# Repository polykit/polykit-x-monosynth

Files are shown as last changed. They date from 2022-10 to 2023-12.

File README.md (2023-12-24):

# Polykit X1 Semi Modular Synthesizer

This repository contains schematics, PCB layout files and front panel for an analog, semi modular, patchable synthesizer. It is an interface that works in conjunction with my voice card https://github.com/polykit/polykit-x-voice-card

Specs of the voice card:

* a VCO with saw, pulse and triangle signal
* an envelope generator
* a multimode filter with 8 different filter responses
* an external input
* and a panning stereo output

See voice card repository for a full feature list.

Specs of the semi modular interface:

* a LFO where the waveform can be blended between triangle and pulse signal
* a wave folder
* a two channel mixer where one input can be attenuated
* an additional attenuator
* a buffered multiple
* different offset voltages
* and a power supply
* 3D printable case

Video playlist on its functionality and design process: https://www.youtube.com/watch?v=2grRbG7IwDw&list=PLUKLEU8jmlbHH4_13YZM0MI6ez4gYQPfy

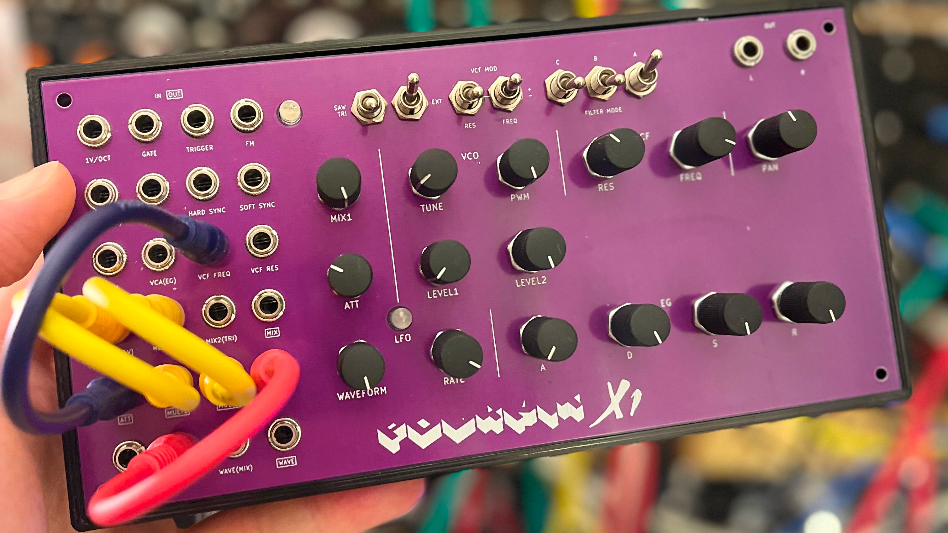
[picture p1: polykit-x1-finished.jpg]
Polykit X1 Semi Modular Synthesizer


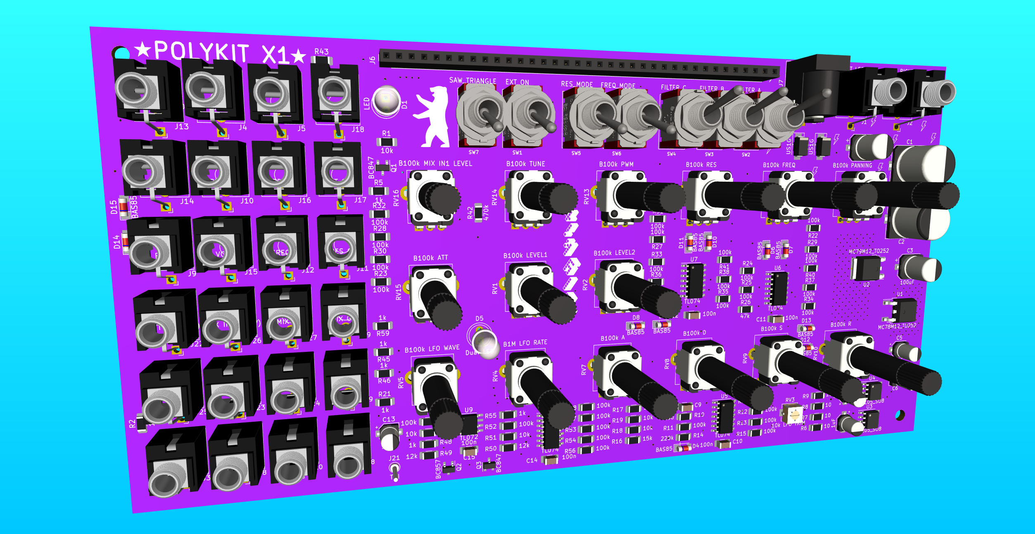
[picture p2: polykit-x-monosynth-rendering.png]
Polykit X1 Semi Modular Synthesizer Rendering


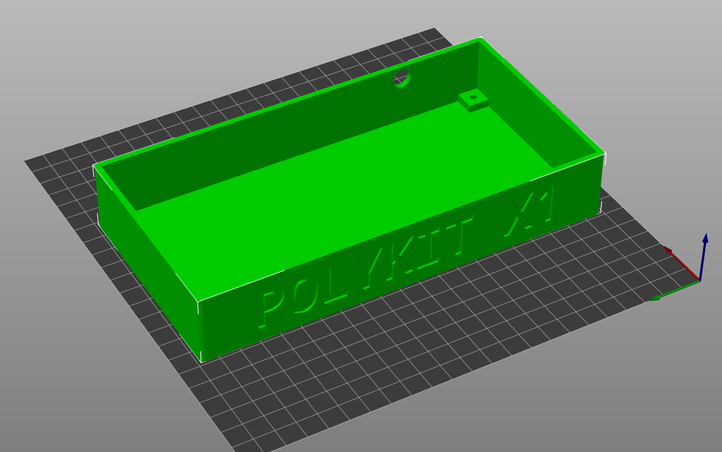
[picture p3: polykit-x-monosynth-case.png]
Polykit X1 Semi Modular Synthesizer Case


Gerber files [can be found here](plots/), front panel files are located [here](frontpanel).

## BOM

|Ref |Qnty|Value |Name |Description |
|---|----|---|---|---|
|C1, C2 |2 |1000uF |C_Polarized |Electrolytic capacitor |
|C3, C4 |2 |100uF |C_Polarized |Electrolytic capacitor |
|C5, C6 |2 |10uF |C_Polarized |Electrolytic capacitor |
|C7, C8 |2 |1uF |C_Polarized |Electrolytic capacitor |
|C9 |1 |2u2 non-polarized |C |Film or ceramic capacitor |
|C10, C11, C12, C13, C14 |5 |100n |C |Ceramic capacitor |
|D1 |1 |LED |LED |Light emitting diode |
|D2, D3 |2 |US1G |US1G |400V, 1A, General Purpose Rectifier Diode, SMA(DO-214AC) |
|D4, D6, D7, D8, D9, D10, D11, D12, D13, D14, D15 |11  |BAS85 |D_Schottky |Schottky diode |
|D5 |1 |Dual LED |LED_Dual_Bidirectional|Dual LED, bidirectional |
|J1 |1 |OUT LEFT |AudioJack2_SwitchT |Audio Jack, 2 Poles (Mono / TS), https://www.thonk.co.uk/shop/thonkiconn|
|J2 |1 |OUT RIGHT |AudioJack2_SwitchT |Audio Jack, 2 Poles (Mono / TS), https://www.thonk.co.uk/shop/thonkiconn|
|J3 |1 |ADSR_OUT |AudioJack2_SwitchT |Audio Jack, 2 Poles (Mono / TS), https://www.thonk.co.uk/shop/thonkiconn|
|J4 |1 |GATE |AudioJack2_SwitchT |Audio Jack, 2 Poles (Mono / TS), https://www.thonk.co.uk/shop/thonkiconn|
|J5 |1 |TRIGGER |AudioJack2_SwitchT |Audio Jack, 2 Poles (Mono / TS), https://www.thonk.co.uk/shop/thonkiconn|
|J6 |1 |Conn_01x36 |Conn_01x36 |Pinheader, 01x36 |
|J7 |1 |12V AC |Jack-DC |Barrel Jack Socket, 12V AC/AC 1A wall wart power supply is needed |
|J8 |1 |LFO |AudioJack2_SwitchT |Audio Jack, 2 Poles (Mono / TS), https://www.thonk.co.uk/shop/thonkiconn|
|J9 |1 |PAN_CV |AudioJack2_SwitchT |Audio Jack, 2 Poles (Mono / TS), https://www.thonk.co.uk/shop/thonkiconn|
|J10 |1 |PWM CV |AudioJack2_SwitchT |Audio Jack, 2 Poles (Mono / TS), https://www.thonk.co.uk/shop/thonkiconn|
|J11 |1 |RES CV |AudioJack2_SwitchT |Audio Jack, 2 Poles (Mono / TS), https://www.thonk.co.uk/shop/thonkiconn|
|J12 |1 |FREQ CV |AudioJack2_SwitchT |Audio Jack, 2 Poles (Mono / TS), https://www.thonk.co.uk/shop/thonkiconn|
|J13 |1 |PITCH CV 1V/OCT |AudioJack2_SwitchT |Audio Jack, 2 Poles (Mono / TS), https://www.thonk.co.uk/shop/thonkiconn|
|J14 |1 |EXT IN |AudioJack2_SwitchT |Audio Jack, 2 Poles (Mono / TS), https://www.thonk.co.uk/shop/thonkiconn|
|J15 |1 |VCA CV |AudioJack2_SwitchT |Audio Jack, 2 Poles (Mono / TS), https://www.thonk.co.uk/shop/thonkiconn|
|J16 |1 |HARD SYNC |AudioJack2_SwitchT |Audio Jack, 2 Poles (Mono / TS), https://www.thonk.co.uk/shop/thonkiconn|
|J17 |1 |SOFT SYNC |AudioJack2_SwitchT |Audio Jack, 2 Poles (Mono / TS), https://www.thonk.co.uk/shop/thonkiconn|
|J18 |1 |FM |AudioJack2_SwitchT |Audio Jack, 2 Poles (Mono / TS), https://www.thonk.co.uk/shop/thonkiconn|
|J19 |1 |MULT |AudioJack2_SwitchT |Audio Jack, 2 Poles (Mono / TS), https://www.thonk.co.uk/shop/thonkiconn|
|J20 |1 |WAVE IN |AudioJack2_SwitchT |Audio Jack, 2 Poles (Mono / TS), https://www.thonk.co.uk/shop/thonkiconn|
|J21 |1 |ATT IN (+5V) |AudioJack2_SwitchT |Audio Jack, 2 Poles (Mono / TS), https://www.thonk.co.uk/shop/thonkiconn|
|J22 |1 |MULT1 |AudioJack2_SwitchT |Audio Jack, 2 Poles (Mono / TS), https://www.thonk.co.uk/shop/thonkiconn|
|J23 |1 |MULT2 |AudioJack2_SwitchT |Audio Jack, 2 Poles (Mono / TS), https://www.thonk.co.uk/shop/thonkiconn|
|J24 |1 |ATT OUT |AudioJack2_SwitchT |Audio Jack, 2 Poles (Mono / TS), https://www.thonk.co.uk/shop/thonkiconn|
|J25 |1 |MIX IN2 | |Can be used as default input for MIX2 when not patched |
|J26 |1 |MIX IN1 (-5V) |AudioJack2_SwitchT |Audio Jack, 2 Poles (Mono / TS), https://www.thonk.co.uk/shop/thonkiconn|
|J27 |1 |MIX IN2 |AudioJack2_SwitchT |Audio Jack, 2 Poles (Mono / TS), https://www.thonk.co.uk/shop/thonkiconn|
|J28 |1 |WAVE OUT |AudioJack2_SwitchT |Audio Jack, 2 Poles (Mono / TS), https://www.thonk.co.uk/shop/thonkiconn|
|J29 |1 |MIX OUT |AudioJack2_SwitchT |Audio Jack, 2 Poles (Mono / TS), https://www.thonk.co.uk/shop/thonkiconn|
|Q1, Q3 |2 |BC847 |BC847 |0.1A Ic, 45V Vce, NPN Transistor, SOT-23 |
|Q2 |1 |BC857 |BC857 |0.1A Ic, 45V Vce, PNP Transistor, SOT-23 |
|R1, R18, R19, R47, R50 |5 |10k |R |Resistor |
|R2, R3, R4, R5, R20, R21, R45, R46, R54, R58 |10  |1k |R |Resistor |
|R10 |1 |100 |R |Resistor |
|R11, R12, R13, R15, R22, R23, R24, R25, R27, R28, R29, R30, R31, R32, R33, R34, R35, R36, R37, R38, R39, R40, R41, R43, R44, R51, R52, R53, R55, R56, R57|31  |100k |R |Resistor |
|R14 |1 |220k |R |Resistor |
|R16 |1 |15k |R |Resistor |
|R17, R48, R49 |3 |12k |R |Resistor |
|R26 |1 |47k |R |Resistor |
|R42 |1 |470k |R |Resistor |
|RV1 |1 |B100k LEVEL1 |R_POT-Device |Potentiometer RK097 Vertical |
|RV2 |1 |B100k LEVEL2 |R_POT-Device |Potentiometer RK097 Vertical |
|RV3 |1 |10k LFO TRIM |R_Potentiometer_Trim  |Trim-potentiometer |
|RV4 |1 |B1M LFO RATE |R_POT-Device |Potentiometer RK097 Vertical |
|RV5 |1 |B100k LFO WAVE |R_POT-Device |Potentiometer RK097 Vertical |
|RV6 |1 |B100k PANNING |R_POT-Device |Potentiometer RK097 Vertical |
|RV7 |1 |B100k A |R_POT-Device |Potentiometer RK097 Vertical |
|RV8 |1 |B100k D |R_POT-Device |Potentiometer RK097 Vertical |
|RV9 |1 |B100k S |R_POT-Device |Potentiometer RK097 Vertical |
|RV10 |1 |B100k R |R_POT-Device |Potentiometer RK097 Vertical |
|RV11 |1 |B100k RES |R_POT-Device |Potentiometer RK097 Vertical |
|RV12 |1 |B100k FREQ |R_POT-Device |Potentiometer RK097 Vertical |
|RV13 |1 |B100k PWM |R_POT-Device |Potentiometer RK097 Vertical |
|RV14 |1 |B100k TUNE |R_POT-Device |Potentiometer RK097 Vertical |
|RV15 |1 |B100k ATT |R_POT-Device |Potentiometer RK097 Vertical |
|RV16 |1 |B100k MIX IN1 LEVEL|R_POT-Device |Potentiometer RK097 Vertical |
|SW1 |1 |EXT_ON |SW_SPDT |Switch, single pole double throw |
|SW2 |1 |FILTER_A |SW_SPDT |Switch, single pole double throw |
|SW3 |1 |FILTER_B |SW_SPDT |Switch, single pole double throw |
|SW4 |1 |FILTER_C |SW_SPDT |Switch, single pole double throw |
|SW5 |1 |RES_MODE |SW_SPDT_MSM |Switch, single pole double throw, center OFF position |
|SW6 |1 |FREQ_MODE |SW_SPDT_MSM |Switch, single pole double throw, center OFF position |
|SW7 |1 |SAW_TRIANGLE |SW_SPDT |Switch, single pole double throw |
|U1 |1 |MC78M12_TO252 |78M12 TO-252 |Positive 500mA 35V Linear Regulator, Fixed Output 5V, TO-252 (D-PAK) |
|U2 |1 |MC79M12_TO252 |79M12 TO-252 |Negative 500mA 35V Linear Regulator, Fixed Output -12V, TO-252 (D-PAK)  |
|U3 |1 |L78L05_SO8 |78L05 SO-8 |Positive 100mA 30V Linear Regulator, Fixed Output 5V, SO-8 |
|U4 |1 |L79L05_SO8 |79L05 SO-8 |Negative 100mA -30V Linear Regulator, Fixed Output -5V, SO-8 |
|U5, U6, U7, U8 |4 |TL074 |TL074 |Quad Low-Noise JFET-Input Operational Amplifiers, DIP-14/SOIC-14 |
|U9 |1 |TL072 |TL072 |Dual Low-Noise JFET-Input Operational Amplifiers, DIP-8/SOIC-8 |

## Tuning

See voice card repository for details on tuning. Additional male/female dupont cables are needed in order to get access to the trimpots. Minimal set of connections are ground, all four voltages, PITCH, PWM, ADSR_*, GATE, LVL2, FREQ_CV and outputs.

## Modifications

`SAW` output of the oscillator can be added to `MIX IN2` default input via a 1k resistor, eg. by tapping into the signal between `R1` and `U6` pin 8 on the voice card.

## References

Voice Card: https://github.com/polykit/polykit-x-voice-card

Footprints: https://github.com/polykit/kicad

Wavefolder: https://www.elby-designs.com/webtek/cgs/cgs52/cgs52_folder.html

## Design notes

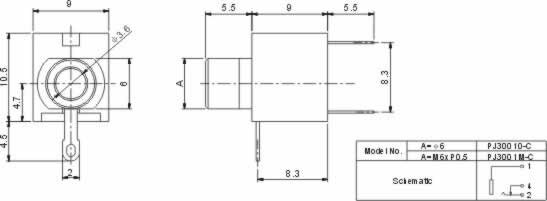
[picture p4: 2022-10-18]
audio-jack-3.5mm-dimensions.jpg

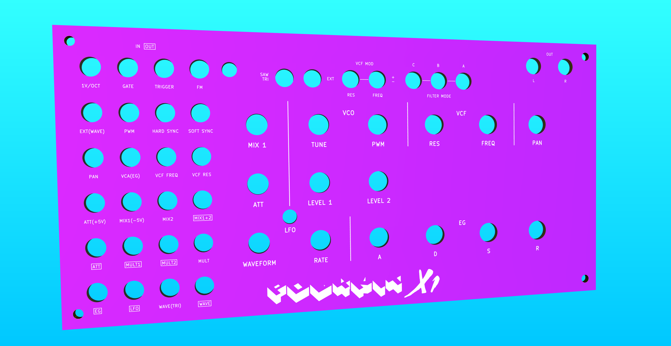
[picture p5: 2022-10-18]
frontpanel/frontpanel-rendering.png

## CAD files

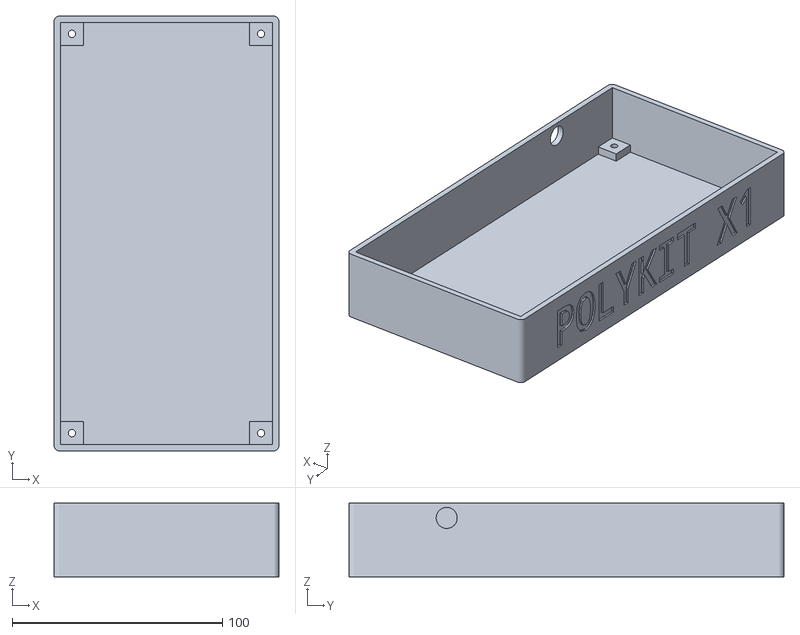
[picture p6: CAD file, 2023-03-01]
stl/Polykit X1 Case.stl
107.0 x 207.0 x 35.0

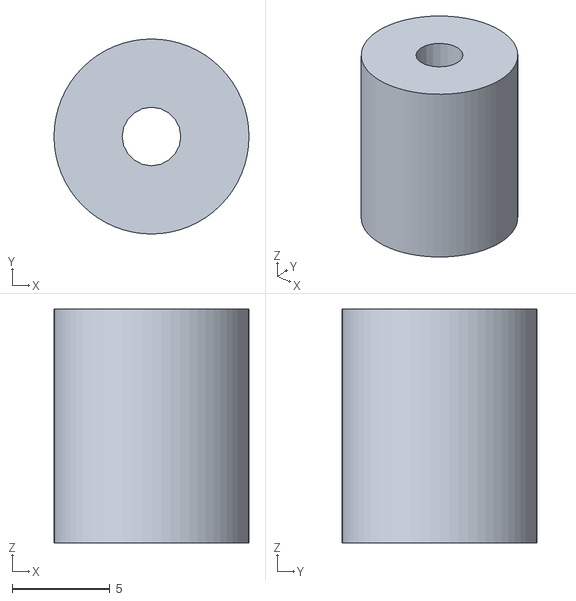
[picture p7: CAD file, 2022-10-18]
stl/Polykit X1 Spacer 12mm.stl
10.0 x 10.0 x 12.0

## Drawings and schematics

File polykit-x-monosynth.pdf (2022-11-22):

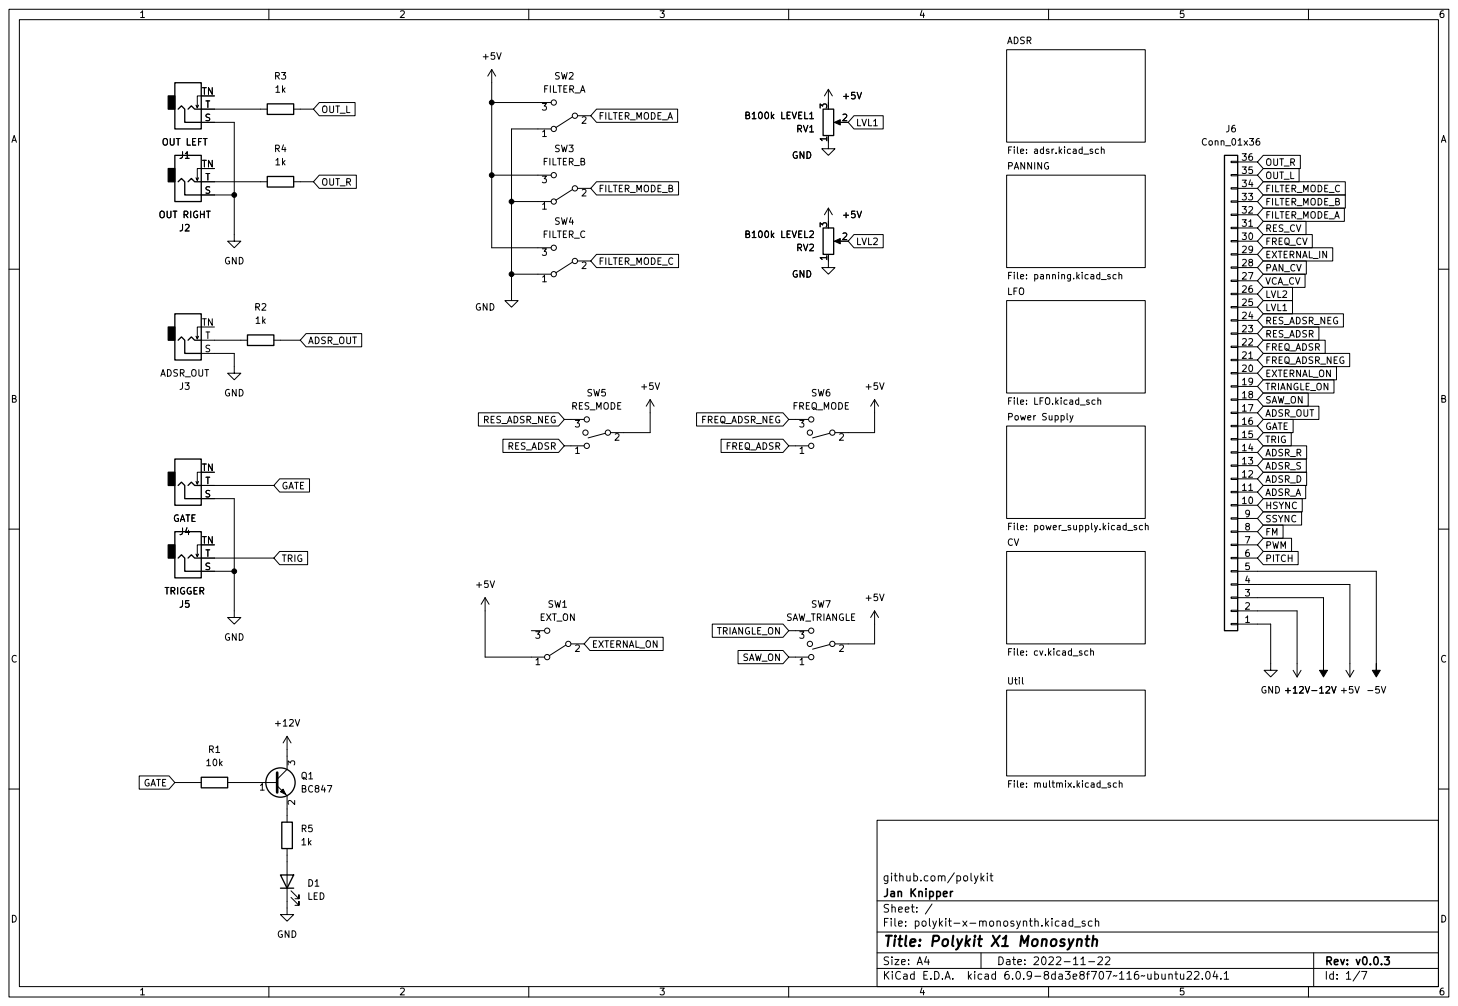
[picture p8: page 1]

github.com/polykit
File: polykit-x-monosynth.kicad_sch Sheet: / Jan Knipper

Id: 1/7 Title: Polykit X1 Monosynth

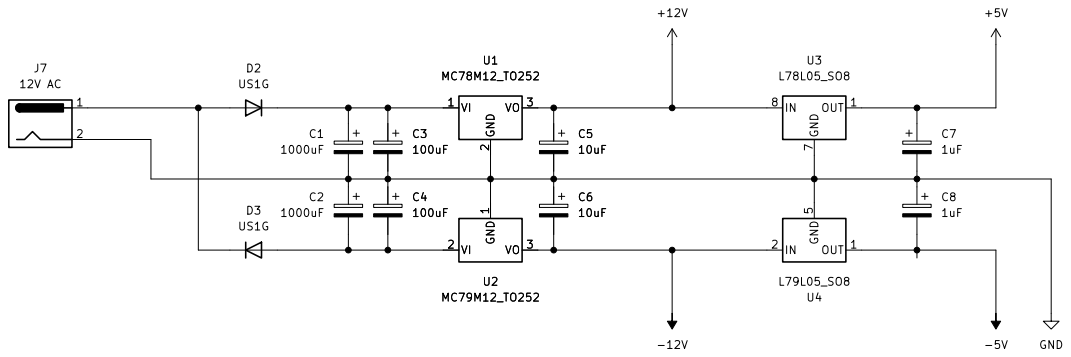
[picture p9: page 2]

Jan Knipper
Sheet: /Power Supply/
File: power_supply.kicad_sch
Id: 2/7 Title: Polykit X1 Monosynth

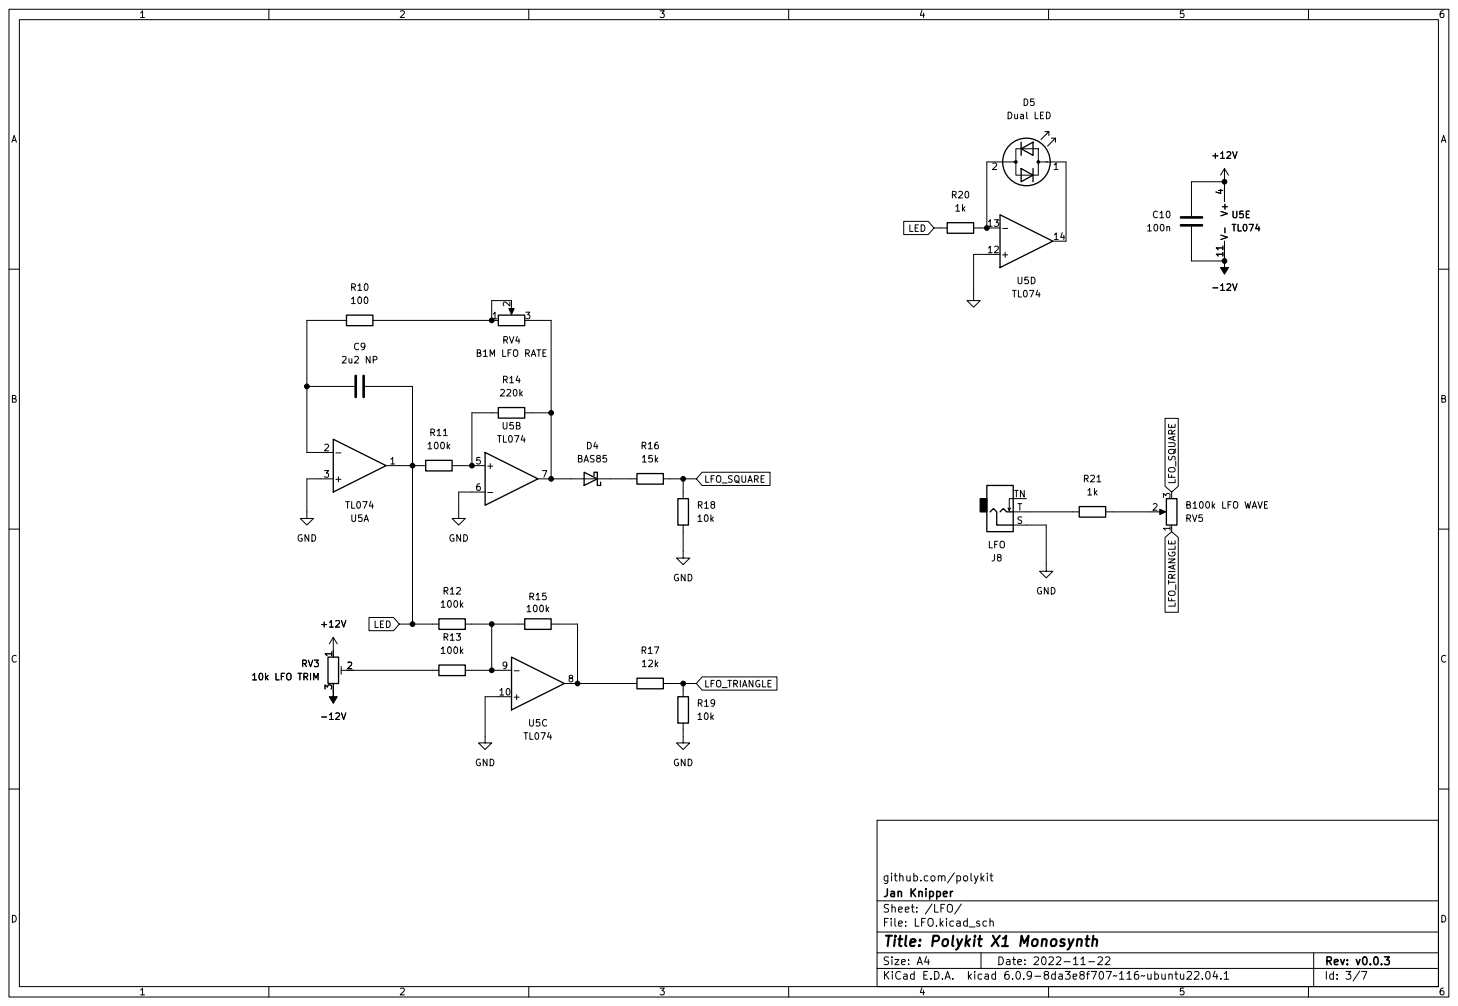
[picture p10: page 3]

File: LFO.kicad_sch Sheet: /LFO/ Jan Knipper

Id: 3/7 Title: Polykit X1 Monosynth

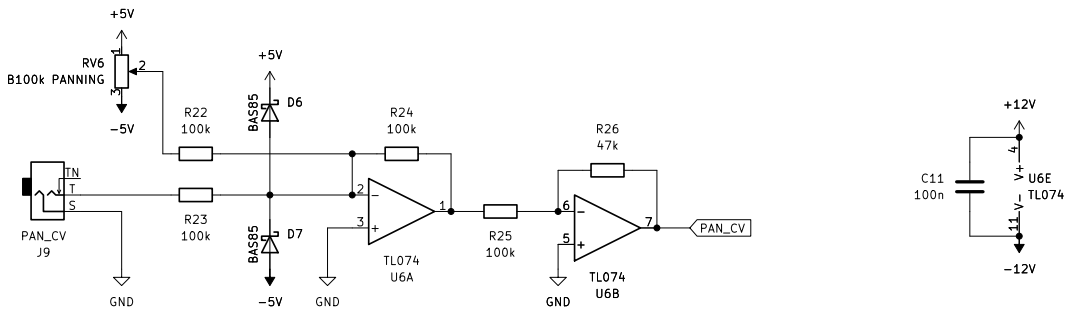
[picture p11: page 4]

github.com/polykit
File: panning.kicad_sch Sheet: /PANNING/ Jan Knipper

Id: 4/7 Title: Polykit X1 Monosynth

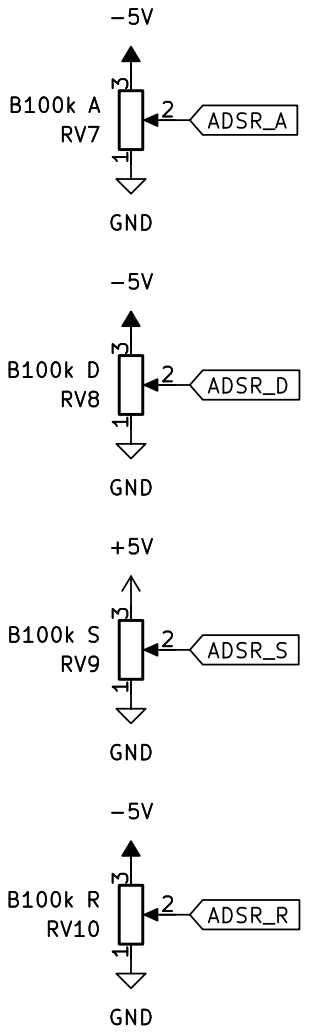
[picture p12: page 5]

github.com/polykit GND GND
-5V GND

File: adsr.kicad_sch Sheet: /ADSR/ Jan Knipper

Id: 5/7 Title: Polykit X1 Monosynth

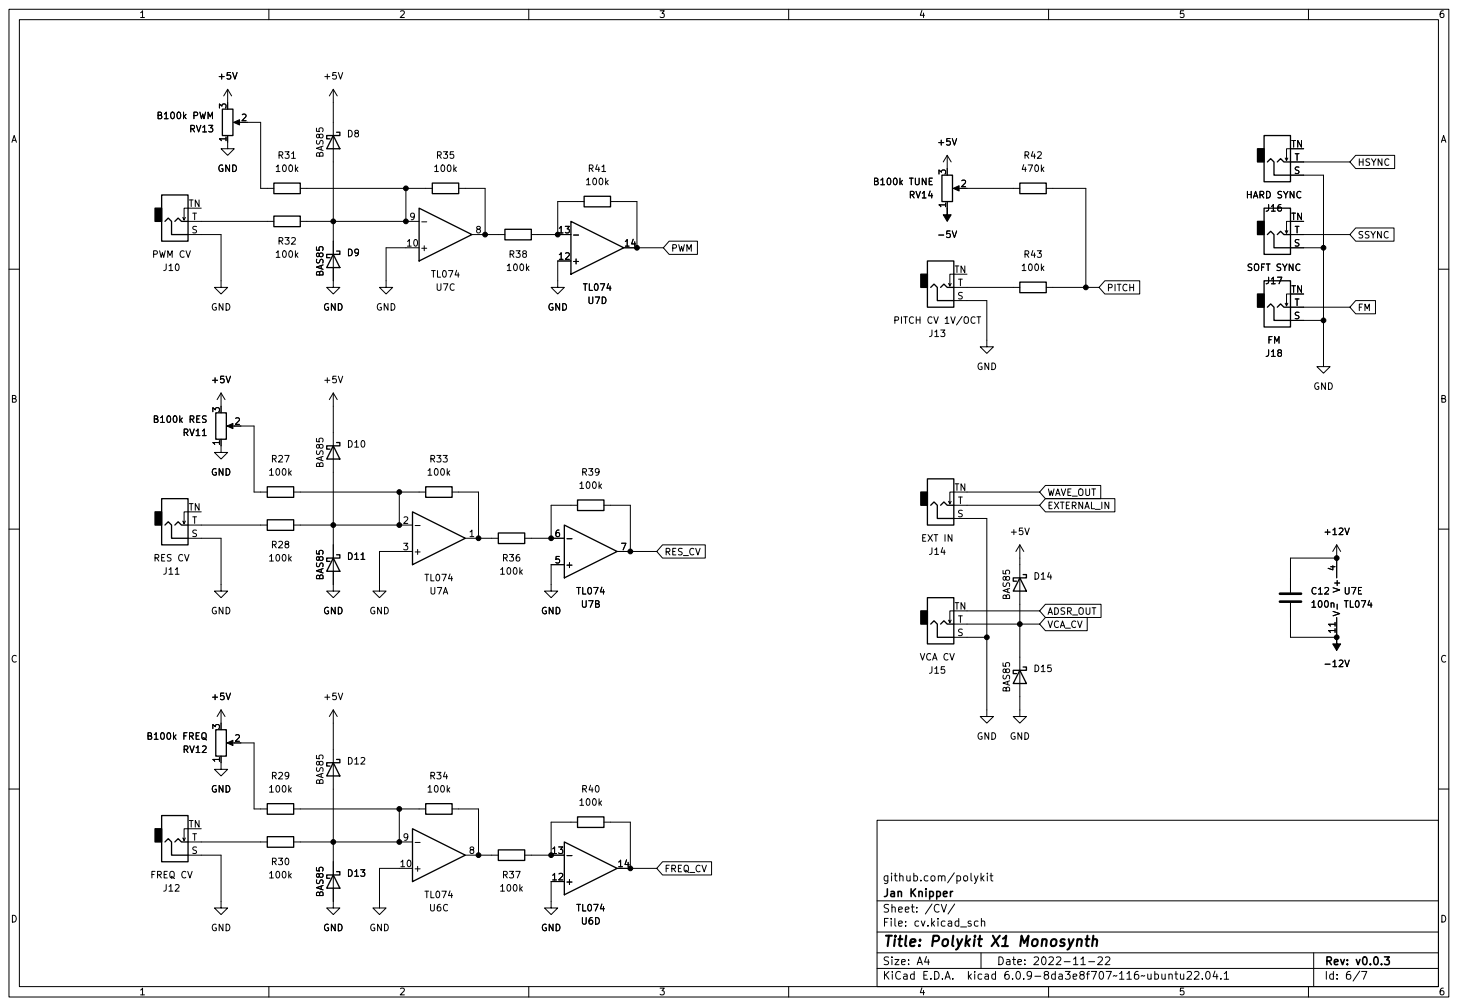
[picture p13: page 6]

File: cv.kicad_sch Sheet: /CV/ Jan Knipper

Id: 6/7 Title: Polykit X1 Monosynth

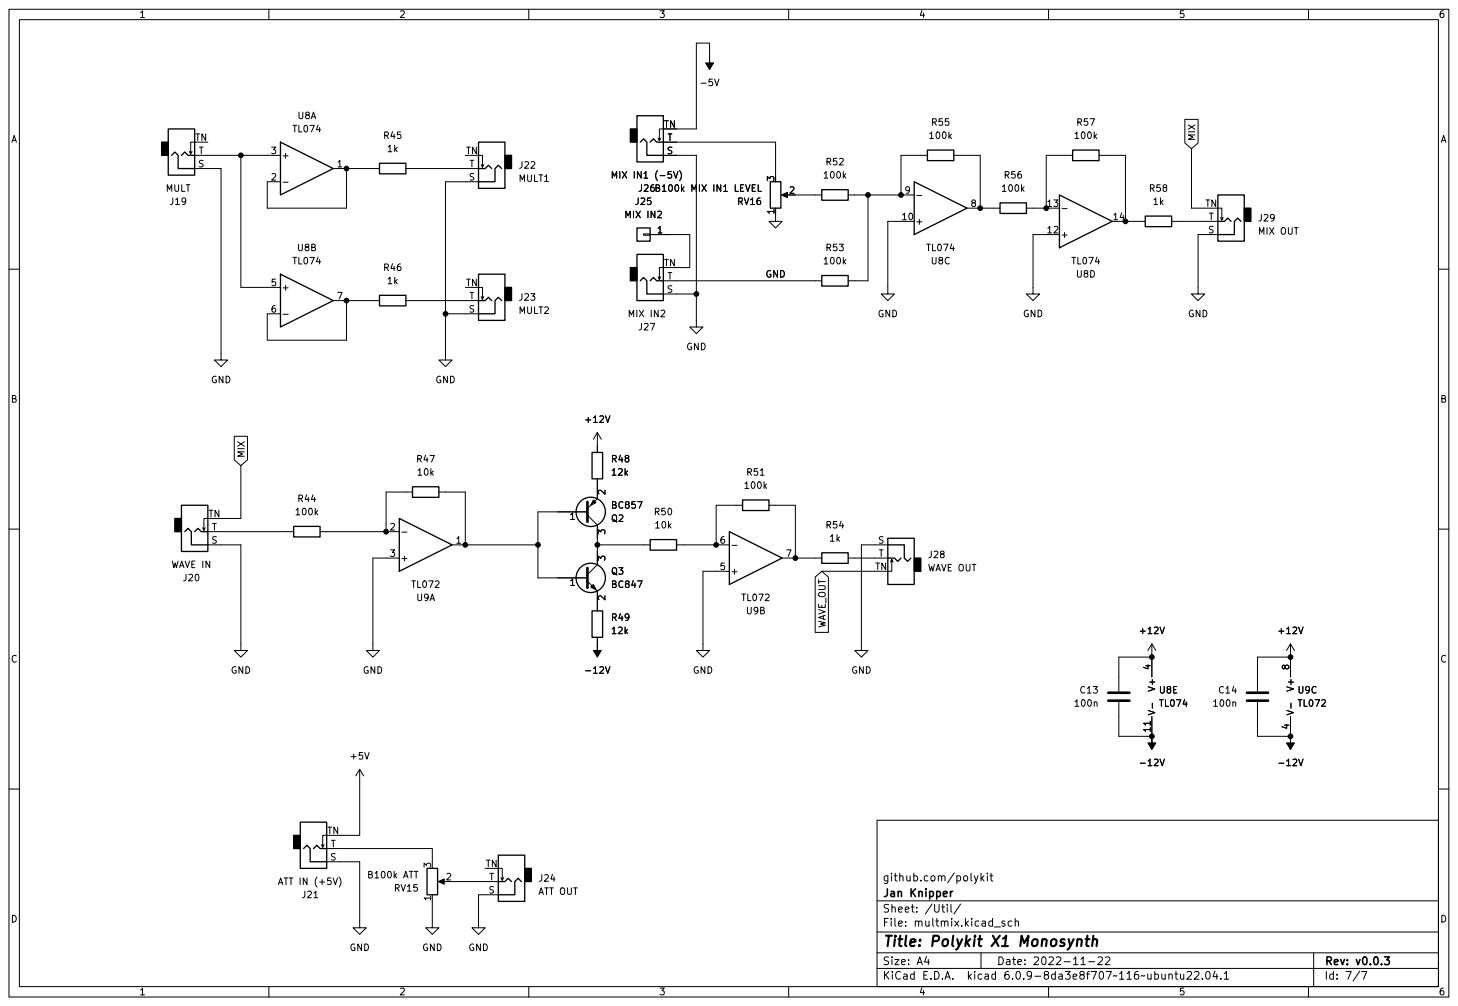
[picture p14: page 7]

File: multmix.kicad_sch Sheet: /Util/ Jan Knipper

Id: 7/7 Title: Polykit X1 Monosynth

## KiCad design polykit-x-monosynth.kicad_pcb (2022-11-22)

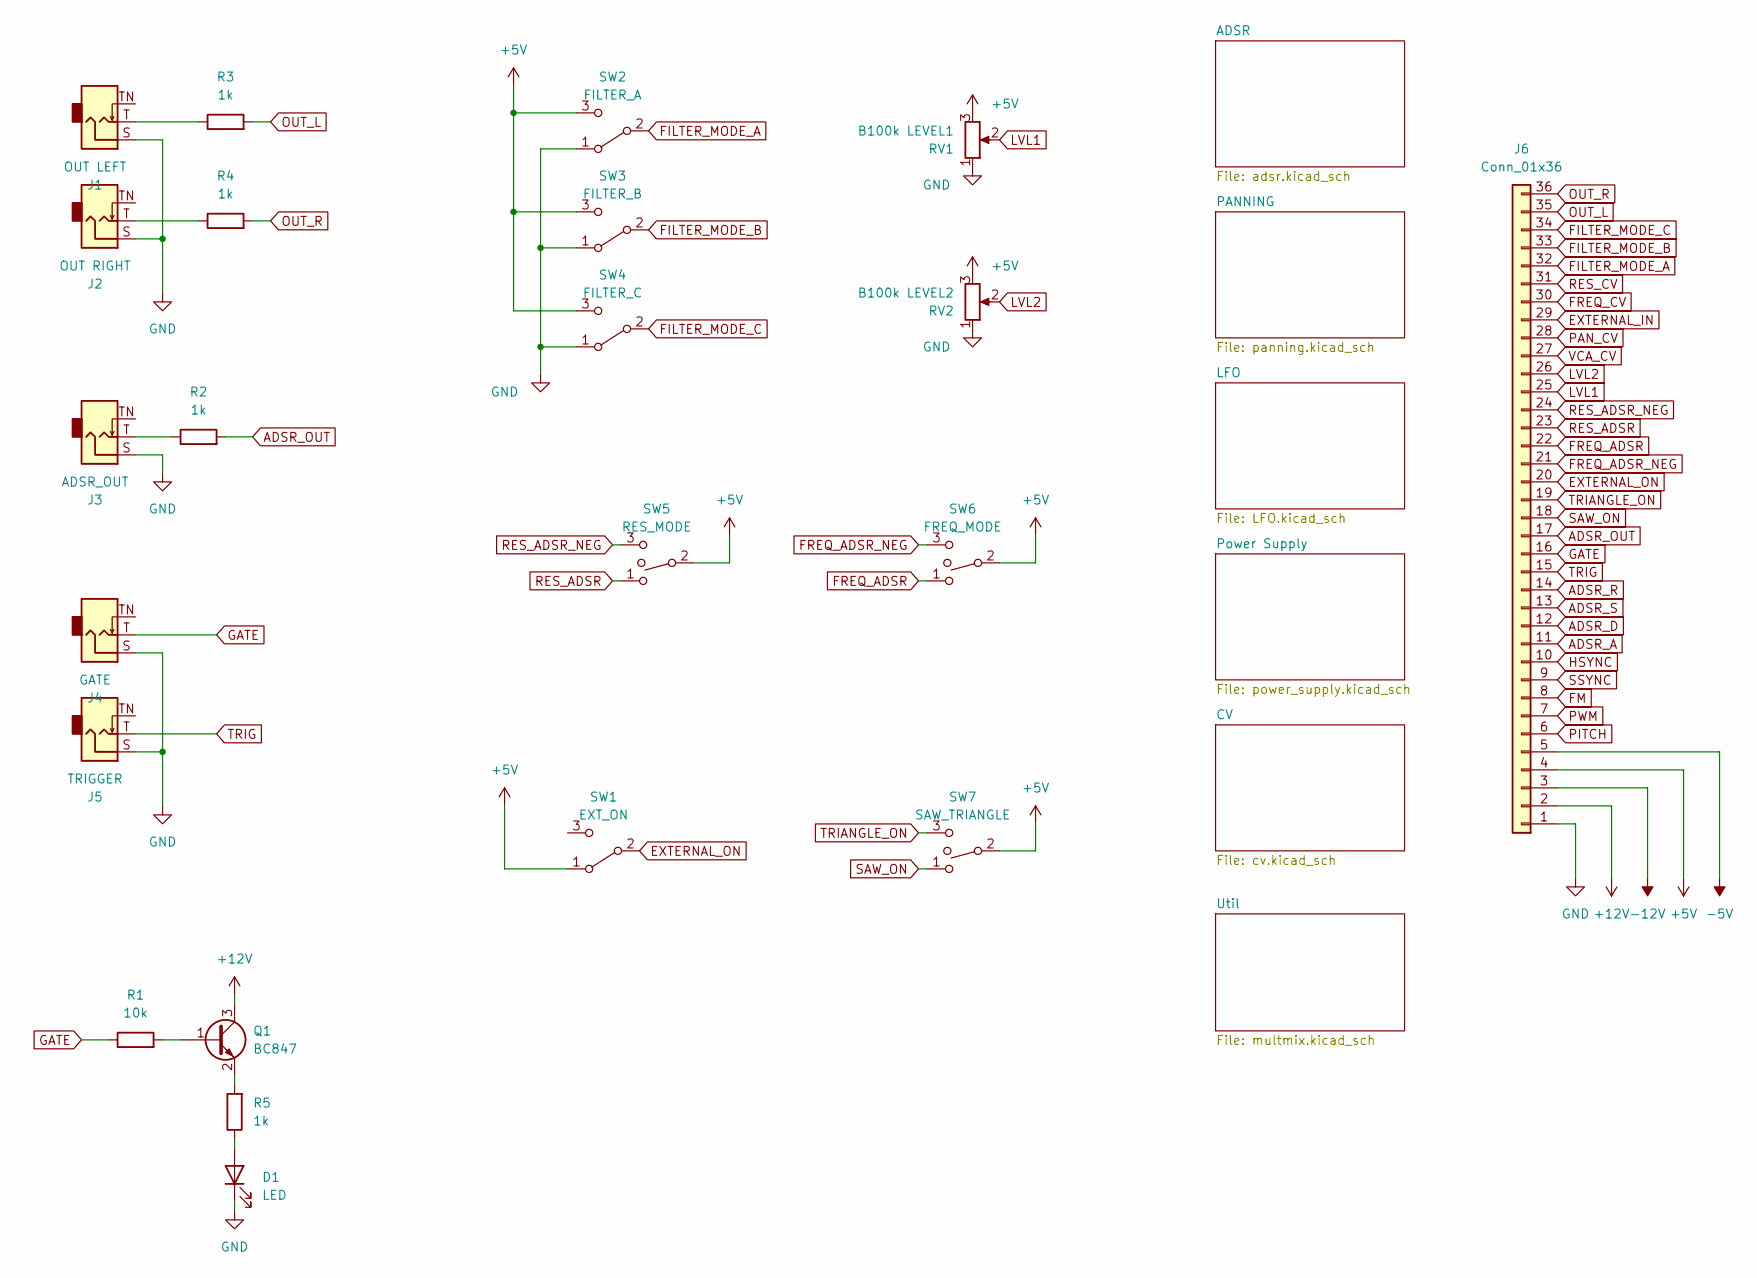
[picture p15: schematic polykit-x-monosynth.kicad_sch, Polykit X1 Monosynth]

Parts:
D1: LED; LED_D5.0mm
J1: OUT LEFT; Jack_3.5mm_QingPu_WQP-PJ398SM_Vertical_CircularHoles
J2: OUT RIGHT; Jack_3.5mm_QingPu_WQP-PJ398SM_Vertical_CircularHoles
J3: ADSR_OUT; Jack_3.5mm_QingPu_WQP-PJ398SM_Vertical_CircularHoles
J4: GATE; Jack_3.5mm_QingPu_WQP-PJ398SM_Vertical_CircularHoles
J5: TRIGGER; Jack_3.5mm_QingPu_WQP-PJ398SM_Vertical_CircularHoles
J6: Conn_01x36; PinSocket_1x36_P2.54mm_Vertical
Q1: BC847; SOT-23; LCSC C8659
R1: 10k; R_1206_3216Metric_Pad1.30x1.75mm_HandSolder; LCSC C17902
R2, R3, R4, R5: 1k; R_1206_3216Metric_Pad1.30x1.75mm_HandSolder; LCSC C4410
RV1: B100k LEVEL1; Potentiometer_Alpha_RD901F-40-00D_Single_Vertical_CircularH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
RV2: B100k LEVEL2; Potentiometer_Alpha_RD901F-40-00D_Single_Vertical_CircularH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
SW1: EXT_ON; switch-spdt
SW2: FILTER_A; switch-spdt
SW3: FILTER_B; switch-spdt
SW4: FILTER_C; switch-spdt
SW5: RES_MODE; switch-spdt
SW6: FREQ_MODE; switch-spdt
SW7: SAW_TRIANGLE; switch-spdt

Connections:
+5V: J6.4, RV1.3, RV2.3, SW1.1 (A), SW2.3 (C), SW3.3 (C), SW4.3 (C), SW5.2, SW6.2, SW7.2; also elsewhere on the board
+12V: J6.2, Q1.3 (C); also elsewhere on the board
-5V: J6.5; also elsewhere on the board
-12V: J6.3; also elsewhere on the board
ADSR_A: J6.11; also elsewhere on the board
ADSR_D: J6.12; also elsewhere on the board
ADSR_OUT: J6.17, R2.2; also elsewhere on the board
ADSR_R: J6.14; also elsewhere on the board
ADSR_S: J6.13; also elsewhere on the board
EXTERNAL_IN: J6.29; also elsewhere on the board
EXTERNAL_ON: J6.20, SW1.2 (B)
FILTER_MODE_A: J6.32, SW2.2 (B)
FILTER_MODE_B: J6.33, SW3.2 (B)
FILTER_MODE_C: J6.34, SW4.2 (B)
FM: J6.8; also elsewhere on the board
FREQ_ADSR: J6.22, SW6.1
FREQ_ADSR_NEG: J6.21, SW6.3
FREQ_CV: J6.30; also elsewhere on the board
GATE: J4.T, J6.16, R1.1
HSYNC: J6.10; also elsewhere on the board
LVL1: J6.25, RV1.2
LVL2: J6.26, RV2.2
unnamed: D1.2 (A), R5.1
unnamed: J1.T, R3.1
unnamed: J2.T, R4.1
unnamed: J3.T, R2.1
unnamed: Q1.1 (B), R1.2
unnamed: Q1.2 (E), R5.2
OUT_L: J6.35, R3.2
OUT_R: J6.36, R4.2
PAN_CV: J6.28; also elsewhere on the board
PITCH: J6.6; also elsewhere on the board
PWM: J6.7; also elsewhere on the board
RES_ADSR: J6.23, SW5.1
RES_ADSR_NEG: J6.24, SW5.3
RES_CV: J6.31; also elsewhere on the board
SAW_ON: J6.18, SW7.1
SSYNC: J6.9; also elsewhere on the board
TRIANGLE_ON: J6.19, SW7.3
TRIG: J5.T, J6.15
VCA_CV: J6.27; also elsewhere on the board

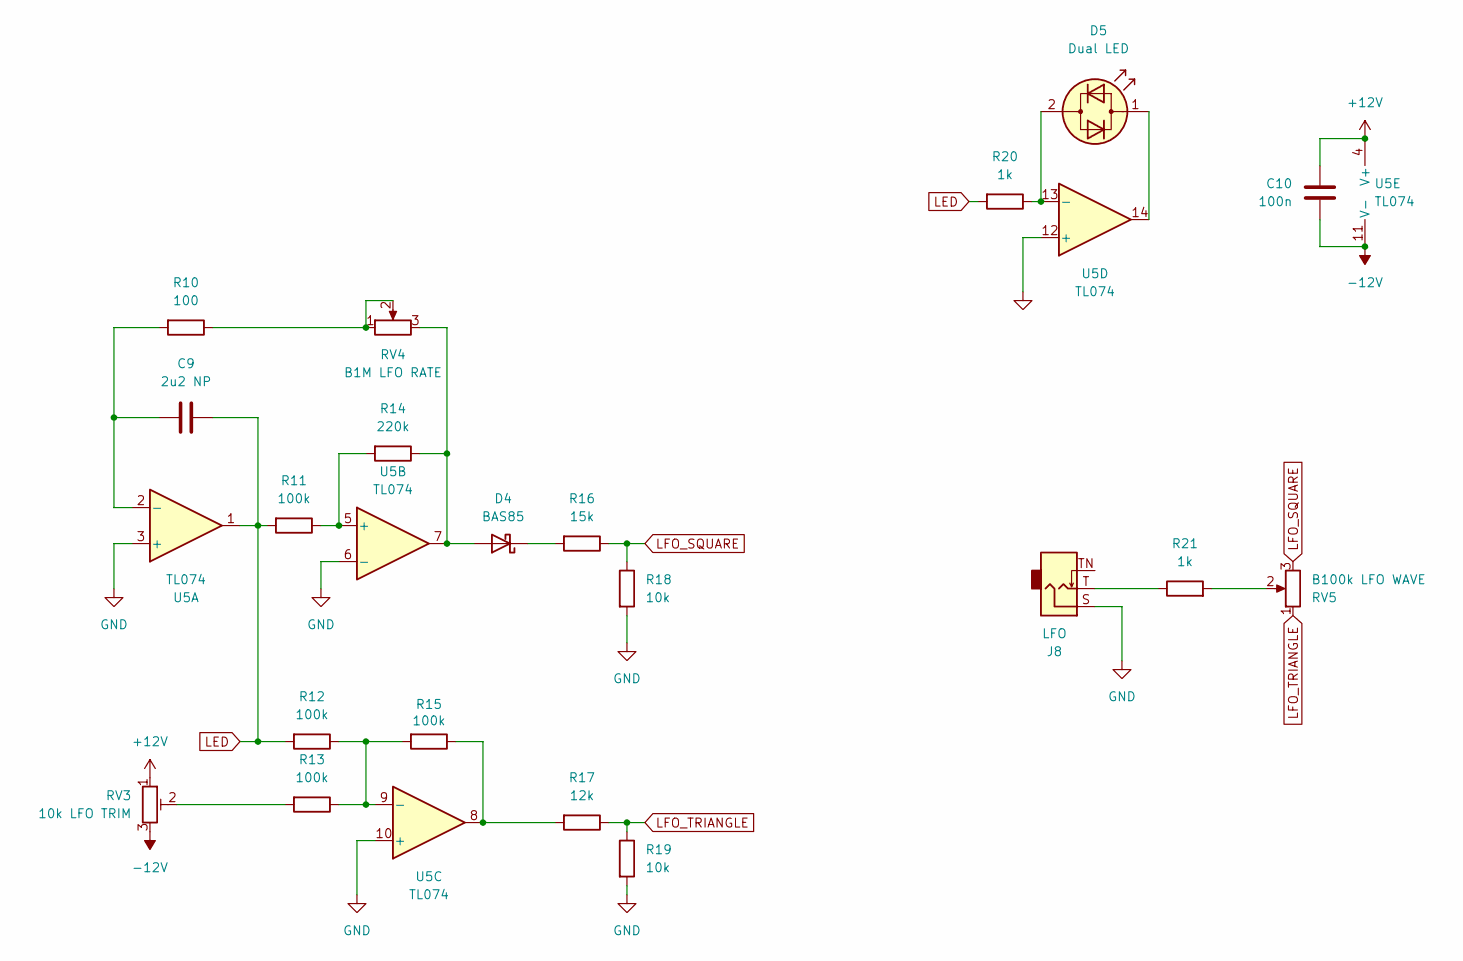
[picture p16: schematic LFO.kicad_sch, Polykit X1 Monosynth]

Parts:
C9: 2u2 NP; C_1206_3216Metric_Pad1.33x1.80mm_HandSolder; LCSC C134236
C10: 100n; C_1206_3216Metric_Pad1.33x1.80mm_HandSolder; LCSC C24497
D4: BAS85; D_MiniMELF; LCSC C46677
D5: Dual LED; LED_D5.0mm
J8: LFO; Jack_3.5mm_QingPu_WQP-PJ398SM_Vertical_CircularHoles
R10: 100; R_1206_3216Metric_Pad1.30x1.75mm_HandSolder; LCSC C17901
R11, R12, R13, R15: 100k; R_1206_3216Metric_Pad1.30x1.75mm_HandSolder; LCSC C17900
R14: 220k; R_1206_3216Metric_Pad1.30x1.75mm_HandSolder; LCSC C17956
R16: 15k; R_1206_3216Metric_Pad1.30x1.75mm_HandSolder; LCSC C17912
R17: 12k; R_1206_3216Metric_Pad1.30x1.75mm_HandSolder; LCSC C17912
R18, R19: 10k; R_1206_3216Metric_Pad1.30x1.75mm_HandSolder; LCSC C17902
R20, R21: 1k; R_1206_3216Metric_Pad1.30x1.75mm_HandSolder; LCSC C4410
RV3: 10k LFO TRIM; Potentiometer_Bourns_3314J_Vertical; LCSC C36376
RV4: B1M LFO RATE; Potentiometer_Alpha_RD901F-40-00D_Single_Vertical_CircularH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
RV5: B100k LFO WAVE; Potentiometer_Alpha_RD901F-40-00D_Single_Vertical_CircularH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
U5: TL074; SO-14_3.9x8.65mm_P1.27mm; LCSC C6963

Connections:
+12V: C10.1, RV3.1, U5.4 (V+); also elsewhere on the board
-12V: C10.2, RV3.3, U5.11 (V-); also elsewhere on the board
LED: C9.1, R11.2, R12.2, R20.2, U5.1
LFO_SQUARE: R16.1, R18.1, RV5.3
LFO_TRIANGLE: R17.1, R19.1, RV5.1
unnamed: C9.2, R10.2, U5.2 (-)
unnamed: D4.1 (K), R16.2
unnamed: D4.2 (A), R14.1, RV4.3, U5.7
unnamed: D5.1 (KA), U5.14
unnamed: D5.2 (AK), R20.1, U5.13 (-)
unnamed: J8.T, R21.1
unnamed: R10.1, RV4.1, RV4.2
unnamed: R11.1, R14.2, U5.5 (+)
unnamed: R12.1, R13.1, R15.2, U5.9 (-)
unnamed: R13.2, RV3.2
unnamed: R15.1, R17.2, U5.8
unnamed: R21.2, RV5.2

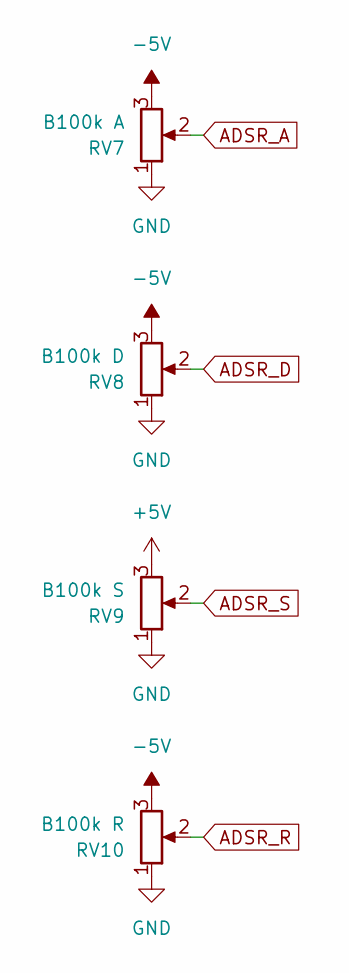
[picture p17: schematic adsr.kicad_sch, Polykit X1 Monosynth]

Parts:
RV7: B100k A; Potentiometer_Alpha_RD901F-40-00D_Single_Vertical_CircularH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
RV8: B100k D; Potentiometer_Alpha_RD901F-40-00D_Single_Vertical_CircularH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
RV9: B100k S; Potentiometer_Alpha_RD901F-40-00D_Single_Vertical_CircularH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
RV10: B100k R; Potentiometer_Alpha_RD901F-40-00D_Single_Vertical_CircularH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

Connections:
+5V: RV9.3; also elsewhere on the board
-5V: RV7.3, RV8.3, RV10.3; also elsewhere on the board
ADSR_A: RV7.2; also elsewhere on the board
ADSR_D: RV8.2; also elsewhere on the board
ADSR_R: RV10.2; also elsewhere on the board
ADSR_S: RV9.2; also elsewhere on the board

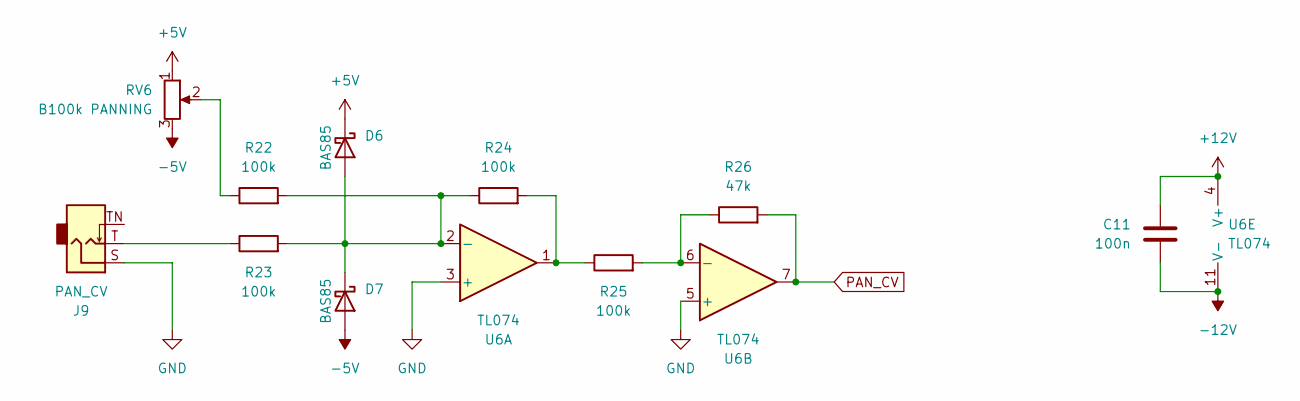
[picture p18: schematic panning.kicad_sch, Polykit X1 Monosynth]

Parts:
C11: 100n; C_1206_3216Metric_Pad1.33x1.80mm_HandSolder; LCSC C24497
D6, D7: BAS85; D_MiniMELF; LCSC C46677
J9: PAN_CV; Jack_3.5mm_QingPu_WQP-PJ398SM_Vertical_CircularHoles
R22, R23, R24, R25: 100k; R_1206_3216Metric_Pad1.30x1.75mm_HandSolder; LCSC C17900
R26: 47k; R_1206_3216Metric_Pad1.30x1.75mm_HandSolder; LCSC C25833
RV6: B100k PANNING; Potentiometer_Alpha_RD901F-40-00D_Single_Vertical_CircularH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
U6: TL074; SO-14_3.9x8.65mm_P1.27mm; LCSC C6963

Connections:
+5V: D6.1 (K), RV6.1; also elsewhere on the board
+12V: C11.1, U6.4 (V+); also elsewhere on the board
-5V: D7.2 (A), RV6.3; also elsewhere on the board
-12V: C11.2, U6.11 (V-); also elsewhere on the board
unnamed: D6.2 (A), D7.1 (K), R22.2, R23.2, R24.1, U6.2 (-)
unnamed: J9.T, R23.1
unnamed: R22.1, RV6.2
unnamed: R24.2, R25.1, U6.1
unnamed: R25.2, R26.1, U6.6 (-)
PAN_CV: R26.2, U6.7; also elsewhere on the board

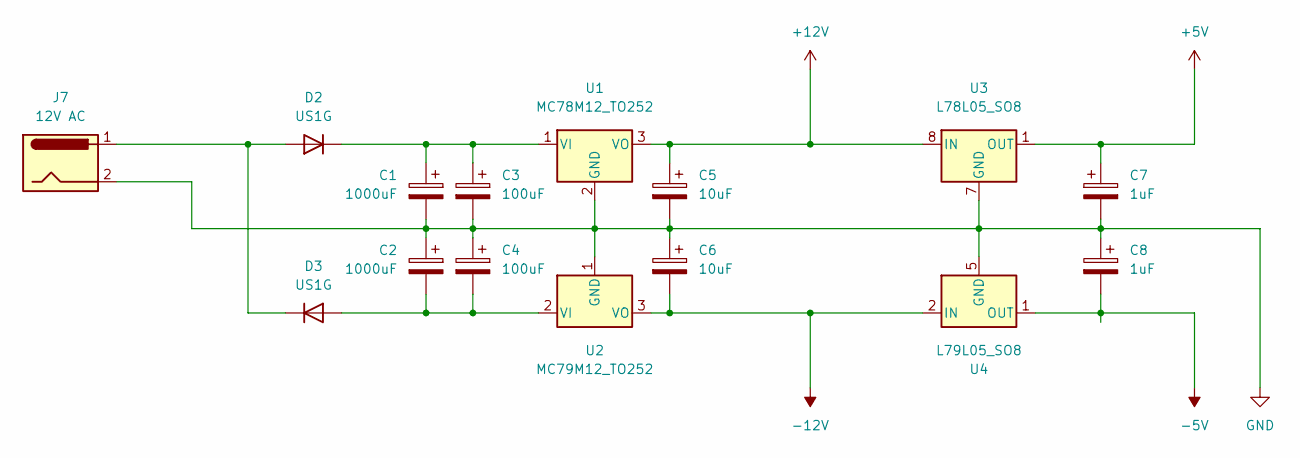
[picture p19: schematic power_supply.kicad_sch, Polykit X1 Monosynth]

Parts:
C1, C2: 1000uF; CP_Elec_10x10; LCSC C2904877*
C3, C4: 100uF; CP_Elec_6.3x7.7; LCSC C125975
C5, C6: 10uF; CP_Elec_4x5.8; LCSC C134237*
C7, C8: 1uF; CP_Elec_4x5.4; LCSC C445065
D2, D3: US1G; D_SMA
J7: 12V AC; BarrelJack_Horizontal
U1: MC78M12_TO252; TO-252-2; LCSC C67851
U2: MC79M12_TO252; TO-252-2; LCSC C154823
U3: L78L05_SO8; SOIC-8_3.9x4.9mm_P1.27mm; LCSC C7372
U4: L79L05_SO8; SOIC-8_3.9x4.9mm_P1.27mm; LCSC C222122

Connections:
+5V: C7.1, U3.1 (OUT); also elsewhere on the board
+12V: C5.1, U1.3 (VO), U3.8 (IN); also elsewhere on the board
-5V: C8.2, U4.1 (OUT); also elsewhere on the board
-12V: C6.2, U2.3 (VO), U4.2 (IN), U4.3 (IN), U4.6 (IN), U4.7 (IN); also elsewhere on the board
unnamed: C1.1, C3.1, D2.1 (K), U1.1 (VI)
unnamed: C2.2, C4.2, D3.2 (A), U2.2 (VI)
unnamed: D2.2 (A), D3.1 (K), J7.1

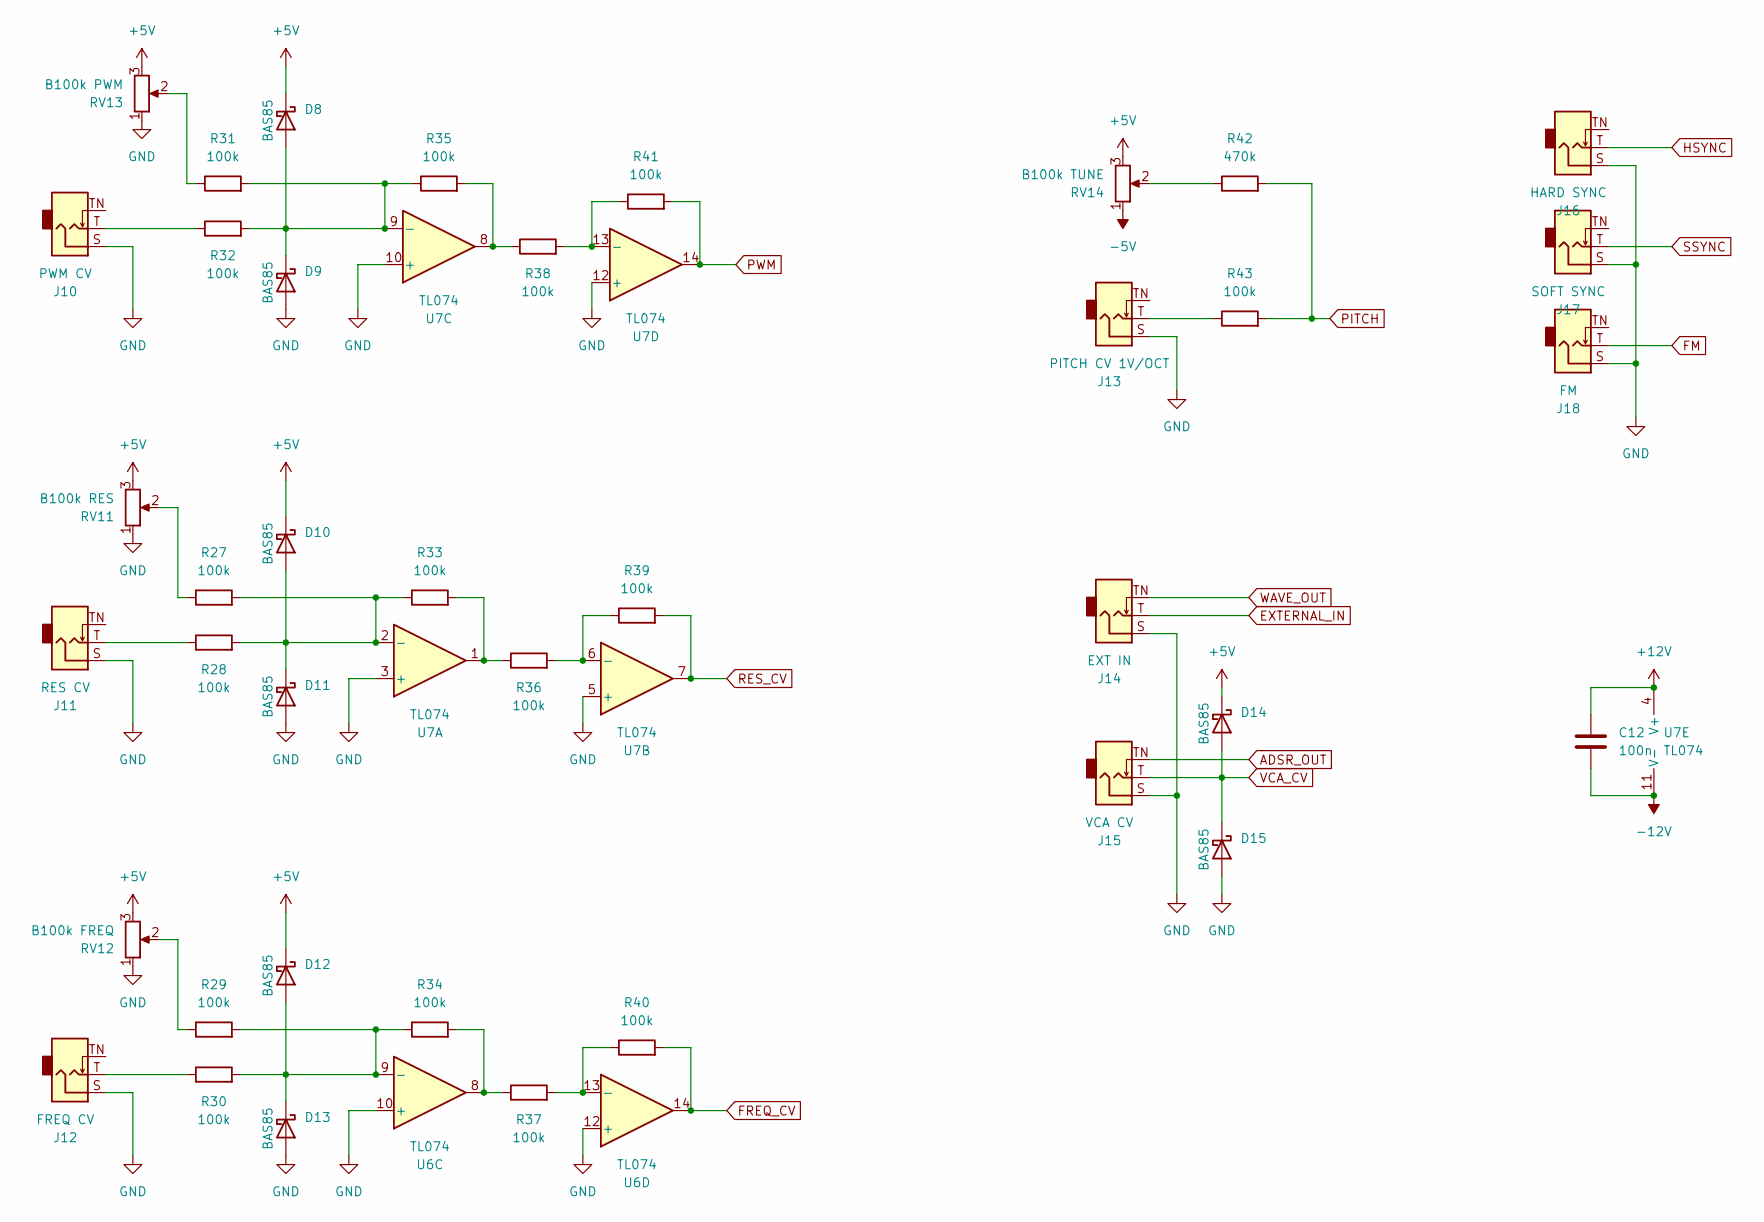
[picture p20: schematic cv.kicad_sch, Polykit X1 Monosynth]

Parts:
C12: 100n; C_1206_3216Metric_Pad1.33x1.80mm_HandSolder; LCSC C24497
D8, D9, D10, D11, D12, D13, D14, D15: BAS85; D_MiniMELF; LCSC C46677
J10: PWM CV; Jack_3.5mm_QingPu_WQP-PJ398SM_Vertical_CircularHoles
J11: RES CV; Jack_3.5mm_QingPu_WQP-PJ398SM_Vertical_CircularHoles
J12: FREQ CV; Jack_3.5mm_QingPu_WQP-PJ398SM_Vertical_CircularHoles
J13: PITCH CV 1V/OCT; Jack_3.5mm_QingPu_WQP-PJ398SM_Vertical_CircularHoles
J14: EXT IN; Jack_3.5mm_QingPu_WQP-PJ398SM_Vertical_CircularHoles
J15: VCA CV; Jack_3.5mm_QingPu_WQP-PJ398SM_Vertical_CircularHoles
J16: HARD SYNC; Jack_3.5mm_QingPu_WQP-PJ398SM_Vertical_CircularHoles
J17: SOFT SYNC; Jack_3.5mm_QingPu_WQP-PJ398SM_Vertical_CircularHoles
J18: FM; Jack_3.5mm_QingPu_WQP-PJ398SM_Vertical_CircularHoles
R27, R28, R29, R30, R31, R32, R33, R34, R35, R36, R37, R38, R39, R40, R41, R43: 100k; R_1206_3216Metric_Pad1.30x1.75mm_HandSolder; LCSC C17900
R42: 470k; R_1206_3216Metric_Pad1.30x1.75mm_HandSolder; LCSC C25663
RV11: B100k RES; Potentiometer_Alpha_RD901F-40-00D_Single_Vertical_CircularH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
RV12: B100k FREQ; Potentiometer_Alpha_RD901F-40-00D_Single_Vertical_CircularH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
RV13: B100k PWM; Potentiometer_Alpha_RD901F-40-00D_Single_Vertical_CircularH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
RV14: B100k TUNE; Potentiometer_Alpha_RD901F-40-00D_Single_Vertical_CircularH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
U6, U7: TL074; SO-14_3.9x8.65mm_P1.27mm; LCSC C6963

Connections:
+5V: D8.1 (K), D10.1 (K), D12.1 (K), D14.1 (K), RV11.3, RV12.3, RV13.3, RV14.3; also elsewhere on the board
+12V: C12.1, U7.4 (V+); also elsewhere on the board
-5V: RV14.1; also elsewhere on the board
-12V: C12.2, U7.11 (V-); also elsewhere on the board
ADSR_OUT: J15.TN; also elsewhere on the board
EXTERNAL_IN: J14.T; also elsewhere on the board
FM: J18.T; also elsewhere on the board
FREQ_CV: R40.2, U6.14; also elsewhere on the board
HSYNC: J16.T; also elsewhere on the board
unnamed: D8.2 (A), D9.1 (K), R31.2, R32.2, R35.1, U7.9 (-)
unnamed: D10.2 (A), D11.1 (K), R27.2, R28.2, R33.1, U7.2 (-)
unnamed: D12.2 (A), D13.1 (K), R29.2, R30.2, R34.1, U6.9 (-)
unnamed: J10.T, R32.1
unnamed: J11.T, R28.1
unnamed: J12.T, R30.1
unnamed: J13.T, R43.1
unnamed: R27.1, RV11.2
unnamed: R29.1, RV12.2
unnamed: R31.1, RV13.2
unnamed: R33.2, R36.1, U7.1
unnamed: R34.2, R37.1, U6.8
unnamed: R35.2, R38.1, U7.8
unnamed: R36.2, R39.1, U7.6 (-)
unnamed: R37.2, R40.1, U6.13 (-)
unnamed: R38.2, R41.1, U7.13 (-)
unnamed: R42.1, RV14.2
PITCH: R42.2, R43.2; also elsewhere on the board
PWM: R41.2, U7.14; also elsewhere on the board
RES_CV: R39.2, U7.7; also elsewhere on the board
SSYNC: J17.T; also elsewhere on the board
VCA_CV: D14.2 (A), D15.1 (K), J15.T; also elsewhere on the board
WAVE_OUT: J14.TN; also elsewhere on the board

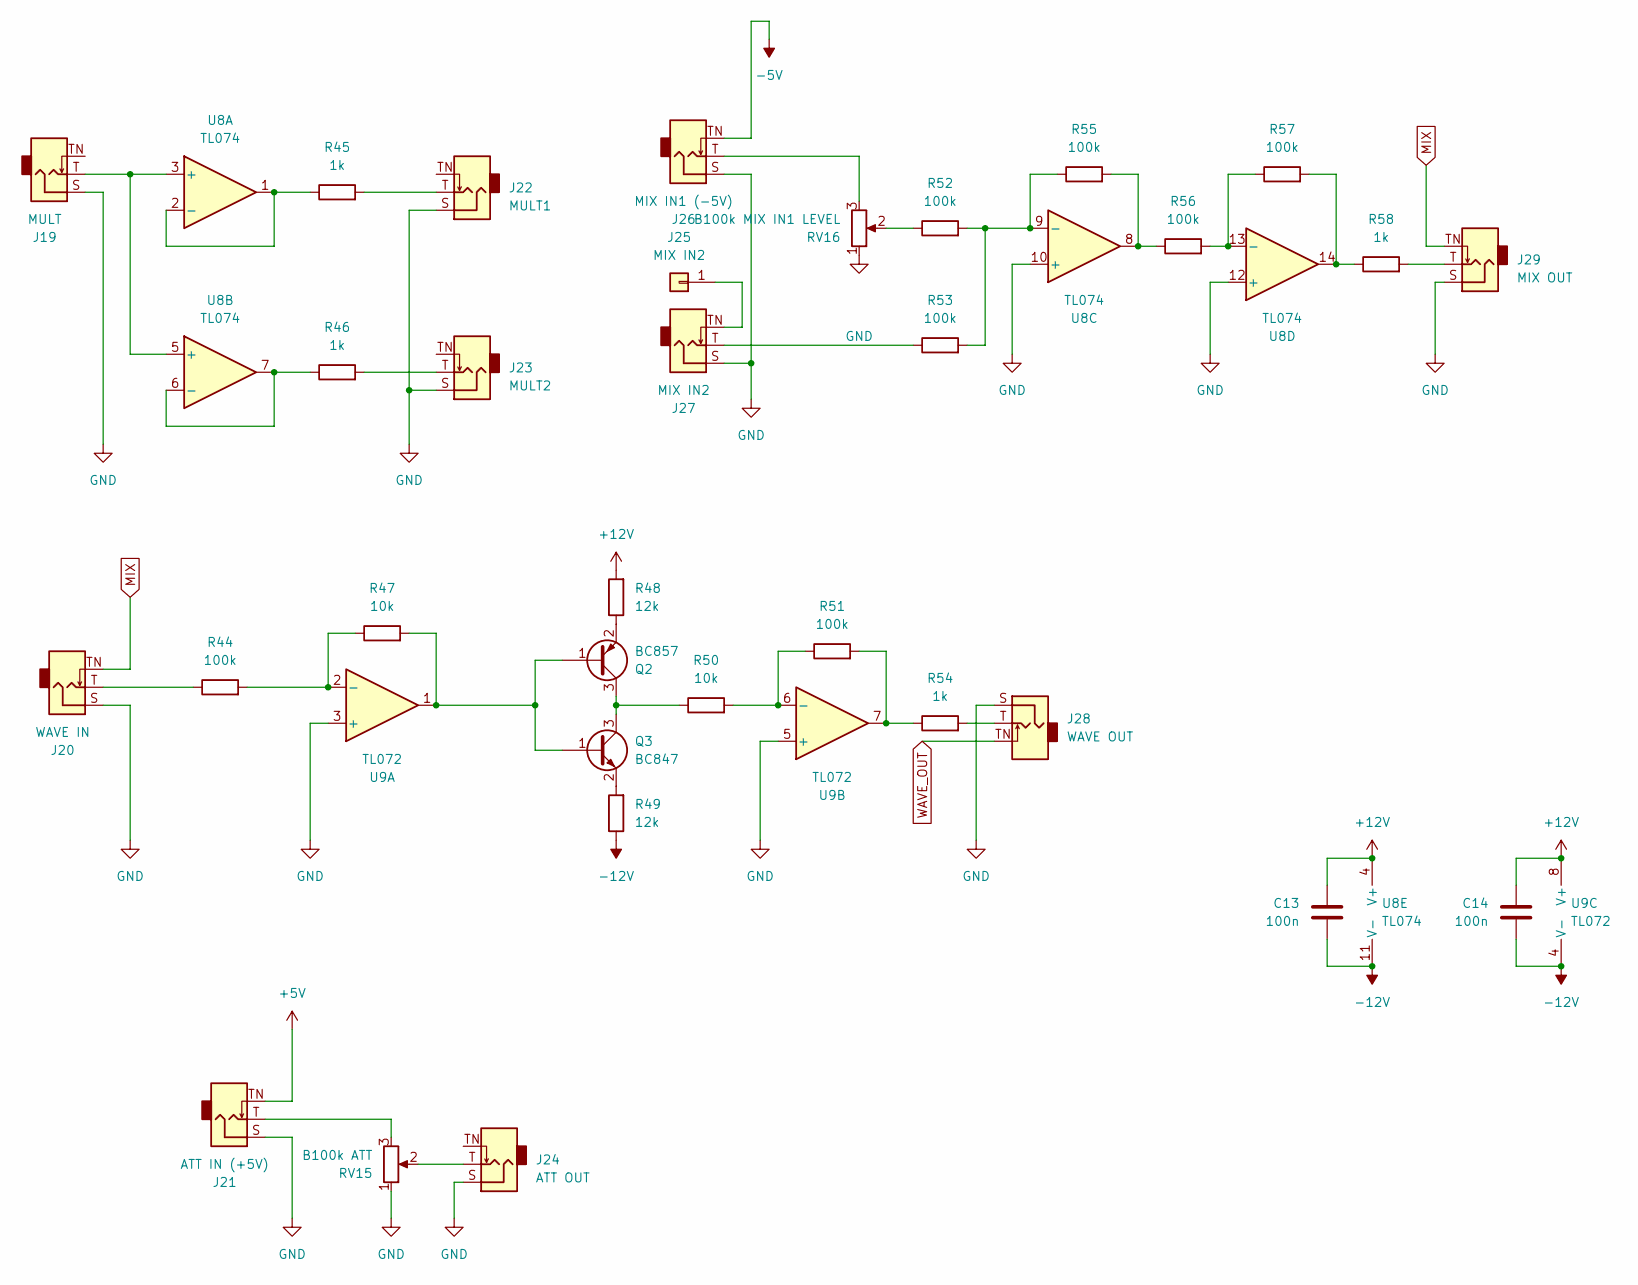
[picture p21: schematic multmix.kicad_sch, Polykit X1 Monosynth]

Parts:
C13, C14: 100n; C_1206_3216Metric_Pad1.33x1.80mm_HandSolder; LCSC C24497
J19: MULT; Jack_3.5mm_QingPu_WQP-PJ398SM_Vertical_CircularHoles
J20: WAVE IN; Jack_3.5mm_QingPu_WQP-PJ398SM_Vertical_CircularHoles
J21: ATT IN (+5V); Jack_3.5mm_QingPu_WQP-PJ398SM_Vertical_CircularHoles
J22: MULT1; Jack_3.5mm_QingPu_WQP-PJ398SM_Vertical_CircularHoles
J23: MULT2; Jack_3.5mm_QingPu_WQP-PJ398SM_Vertical_CircularHoles
J24: ATT OUT; Jack_3.5mm_QingPu_WQP-PJ398SM_Vertical_CircularHoles
J25: MIX IN2; Pin_D1.0mm_L10.0mm
J26: MIX IN1 (-5V); Jack_3.5mm_QingPu_WQP-PJ398SM_Vertical_CircularHoles
J27: MIX IN2; Jack_3.5mm_QingPu_WQP-PJ398SM_Vertical_CircularHoles
J28: WAVE OUT; Jack_3.5mm_QingPu_WQP-PJ398SM_Vertical_CircularHoles
J29: MIX OUT; Jack_3.5mm_QingPu_WQP-PJ398SM_Vertical_CircularHoles
Q2: BC857; SOT-23
Q3: BC847; SOT-23
R44, R51: 100k; R_1206_3216Metric_Pad1.30x1.75mm_HandSolder; LCSC C4410
R45, R46, R54, R58: 1k; R_1206_3216Metric_Pad1.30x1.75mm_HandSolder; LCSC C4410
R47, R50: 10k; R_1206_3216Metric_Pad1.30x1.75mm_HandSolder; LCSC C4410
R48, R49: 12k; R_1206_3216Metric_Pad1.30x1.75mm_HandSolder; LCSC C4410
R52, R53, R55, R56, R57: 100k; R_1206_3216Metric_Pad1.30x1.75mm_HandSolder; LCSC C17900
RV15: B100k ATT; Potentiometer_Alpha_RD901F-40-00D_Single_Vertical_CircularH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
RV16: B100k MIX IN1 LEVEL; Potentiometer_Alpha_RD901F-40-00D_Single_Vertical_CircularH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
U8: TL074; SO-14_3.9x8.65mm_P1.27mm; LCSC C6963
U9: TL072

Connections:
+5V: J21.TN; also elsewhere on the board
+12V: C13.1, C14.1, R48.2, U8.4 (V+), U9.8 (V+); also elsewhere on the board
-5V: J26.TN; also elsewhere on the board
-12V: C13.2, C14.2, R49.1, U8.11 (V-), U9.4 (V-); also elsewhere on the board
MIX: J20.TN, J29.TN
unnamed: J19.T, U8.3 (+), U8.5 (+)
unnamed: J20.T, R44.1
unnamed: J21.T, RV15.3
unnamed: J22.T, R45.2
unnamed: J23.T, R46.2
unnamed: J24.T, RV15.2
unnamed: J25.1, J27.TN
unnamed: J26.T, RV16.3
unnamed: J27.T, R53.1
unnamed: J28.T, R54.2
unnamed: J29.T, R58.2
unnamed: Q2.1 (B), Q3.1 (B), R47.2, U9.1
unnamed: Q2.2 (E), R48.1
unnamed: Q2.3 (C), Q3.3 (C), R50.1
unnamed: Q3.2 (E), R49.2
unnamed: R44.2, R47.1, U9.2 (-)
unnamed: R45.1, U8.1, U8.2 (-)
unnamed: R46.1, U8.6 (-), U8.7
unnamed: R50.2, R51.1, U9.6 (-)
unnamed: R51.2, R54.1, U9.7
unnamed: R52.1, RV16.2
unnamed: R52.2, R53.2, R55.1, U8.9 (-)
unnamed: R55.2, R56.1, U8.8
unnamed: R56.2, R57.1, U8.13 (-)
unnamed: R57.2, R58.1, U8.14
WAVE_OUT: J28.TN; also elsewhere on the board

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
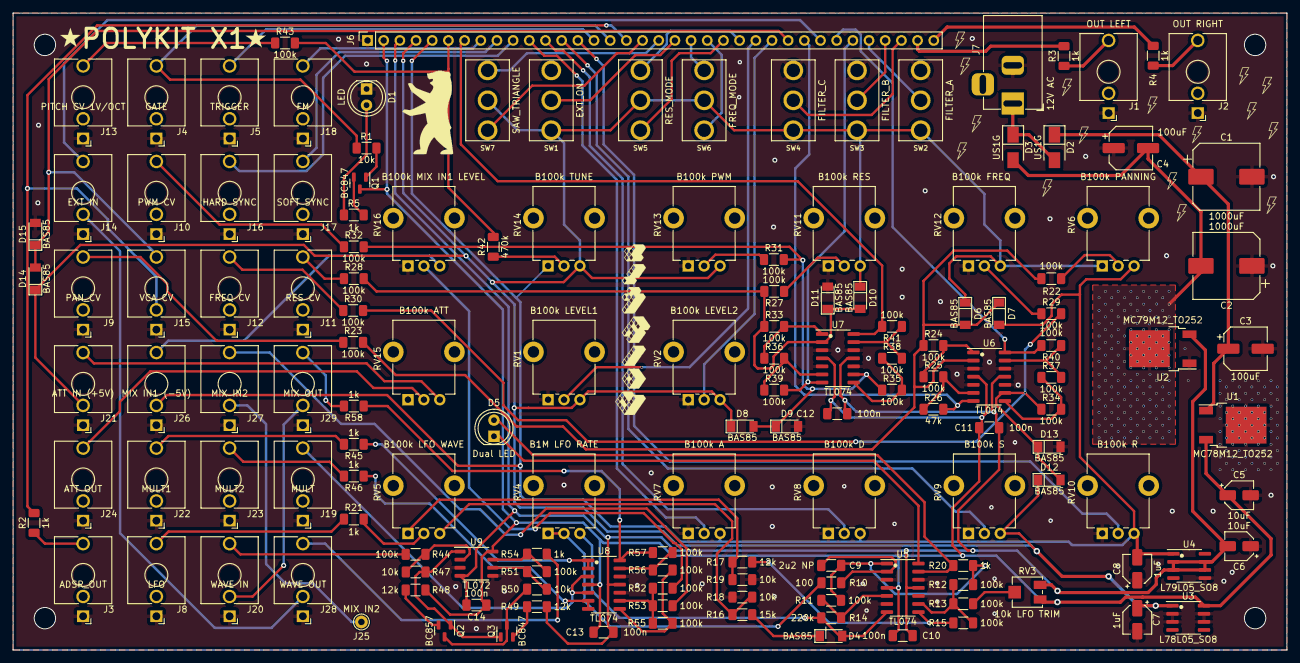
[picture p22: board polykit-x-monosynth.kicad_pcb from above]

Board: 2 copper layers, 200.0 x 100.0 mm, 147 parts (0 on the bottom side), 109 nets.

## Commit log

2022-10-18 Initial import
    [LFO.kicad_sch, Polykit X1 Case.stl, Polykit X1 Spacer 12mm.stl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]
2022-11-22 Fix power supply, add schematics pdf
    [polykit-x-monosynth-B_Cu.gbr, polykit-x-monosynth-B_Mask.gbr, polykit-x-monosynth-B_Paste.gbr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]
2022-11-22 Fix date
    [LFO.kicad_sch, adsr.kicad_sch, cv.kicad_sch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]
2022-12-17 Add bom to readme
2023-03-01 Update case 3d model
    [Polykit X1 Case.stl]
2023-12-24 Add readme modifications and footprint
